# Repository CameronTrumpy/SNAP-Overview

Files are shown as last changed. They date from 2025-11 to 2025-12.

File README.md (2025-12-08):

# SNAP-Overview

SNAP-Overview is our central repository storing all of the relevant information for SNAP, the low-cost modular electronics workstation.

## SNAP-Overview Content
- [Firmware](./Firmware)
    - Mainboard Module Code
    - Oscilloscope / Logic Analyzer Module Code
    - Power Supply / Waveform Generator Module Code
- [docs](./docs)
    - Code for [snapstation.tech](https://snapstation.tech), our project overview website
    - [In-browser demo of our user interface](https://snapstation.tech/demo.html)
- [Hardware](./Hardware)
    - PDF prints of our schematics for all three modules
    - Altium Project archives
    - Translated KiCad Project archived
    - STEP models of the PCB housings
- [WebUI](./WebUI)
    - The frontend and backend for our web-based user interface
- [SigrokPatch](./SigrokPatch)
    - Our modified version of [Sigrok](http://sigrok.org) with support for SNAP
## Contributors
- [Claire Garbowski](https://www.linkedin.com/in/claire-garbowski/)
- [Ethan McKean](https://www.linkedin.com/in/ethanmckean/)
- [Andre Quimper Osores](https://www.linkedin.com/in/andre-q-395964254/)
- [Jack Smith](http://www.linkedin.com/in/jack-smith-561326330)
- [Cameron Trumpy](https://www.linkedin.com/in/cameron-trumpy/)
- [Benjamin Wolin](https://www.linkedin.com/in/benjamin-wolin-8812aa1ab/)

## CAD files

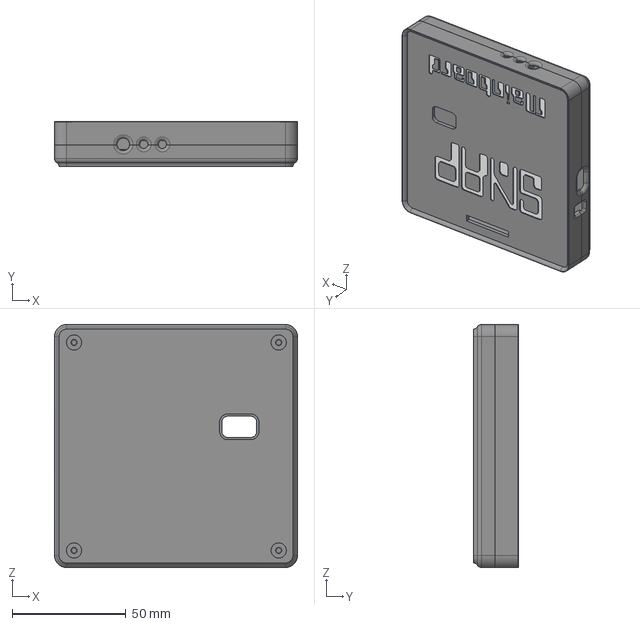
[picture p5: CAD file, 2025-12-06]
Hardware/Mainboard/Mainboard_Housing.step
107.0 x 19.9 x 107.0 mm
Base

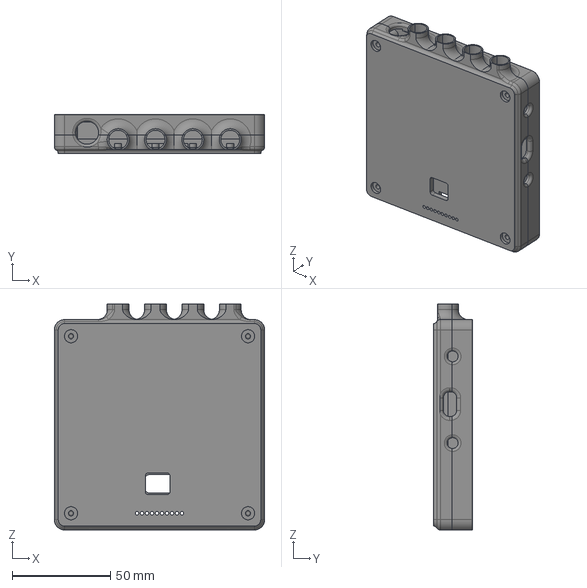
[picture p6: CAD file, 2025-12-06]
Hardware/PD_Waveform/PSU_Housing.step
107.0 x 19.9 x 114.9 mm
Base

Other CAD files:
Hardware/LA_OS/Scope_Housing.step

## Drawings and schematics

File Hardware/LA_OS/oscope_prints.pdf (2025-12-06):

# Mode Pin Settings

# REF Decoupling

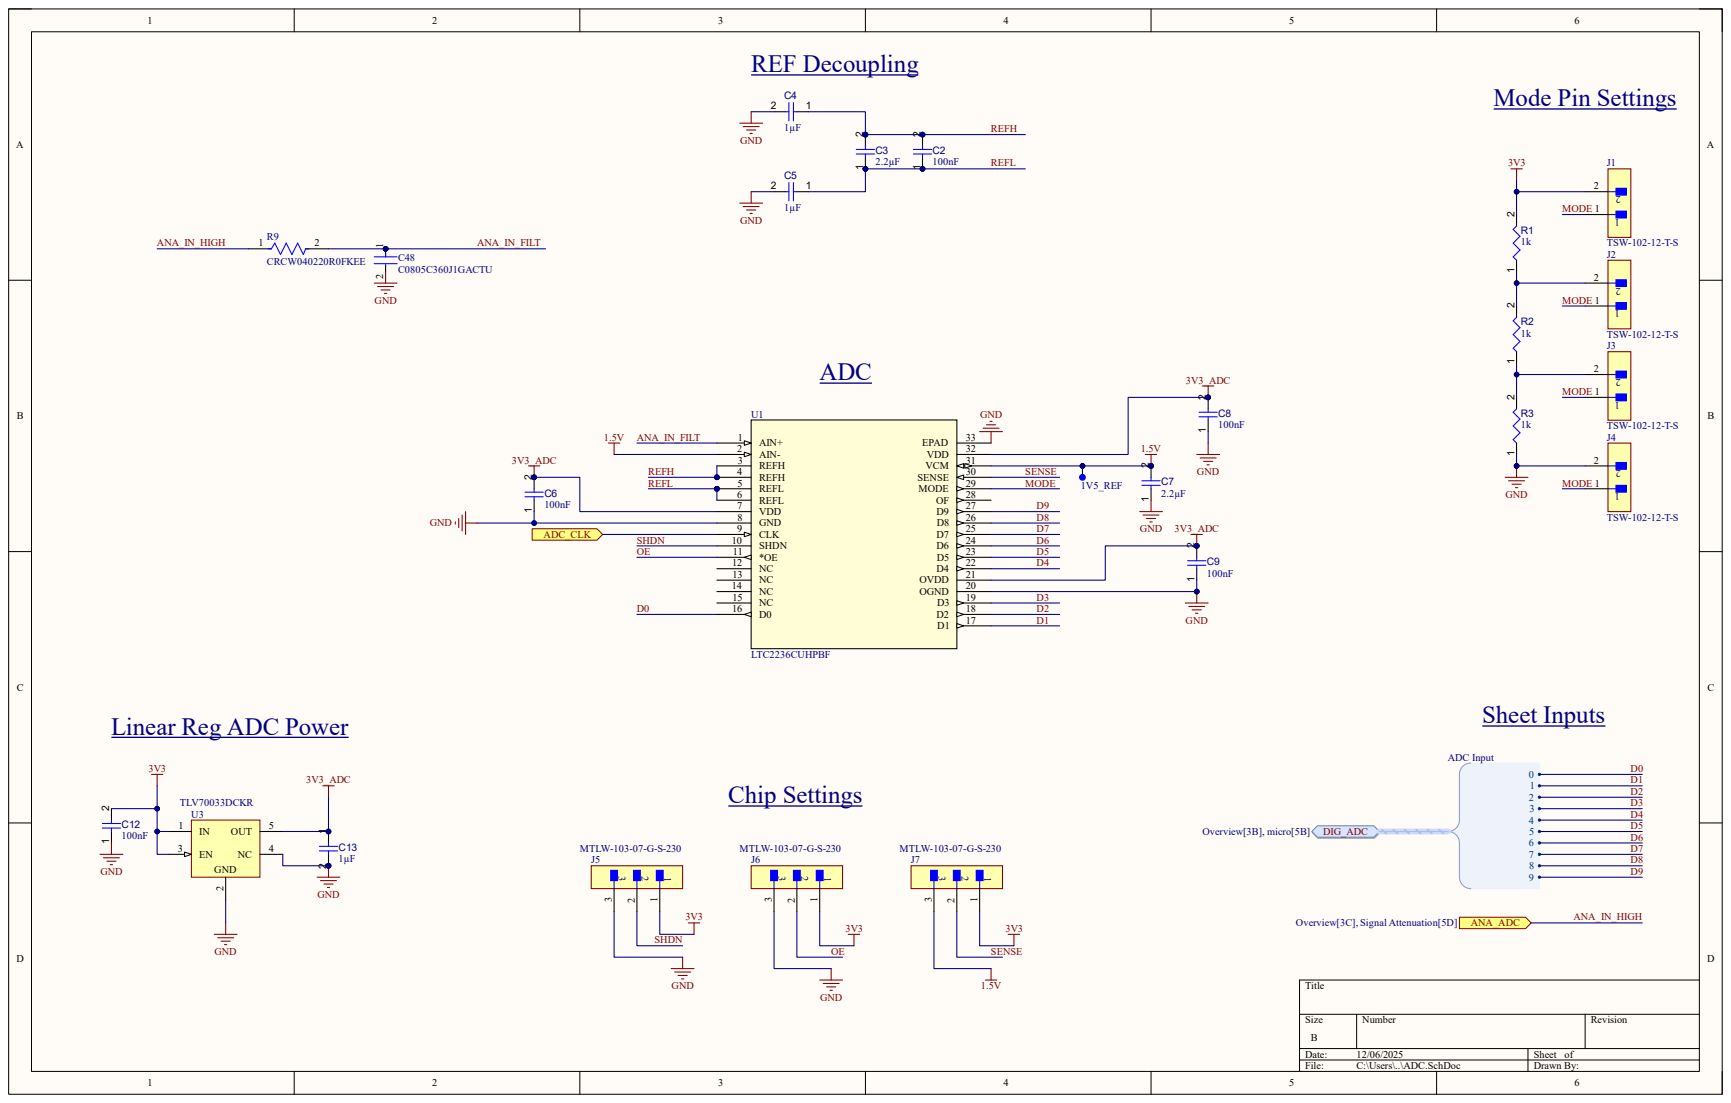
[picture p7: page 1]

Linear Reg ADC Power

A A

ANA_IN | ANA_IN

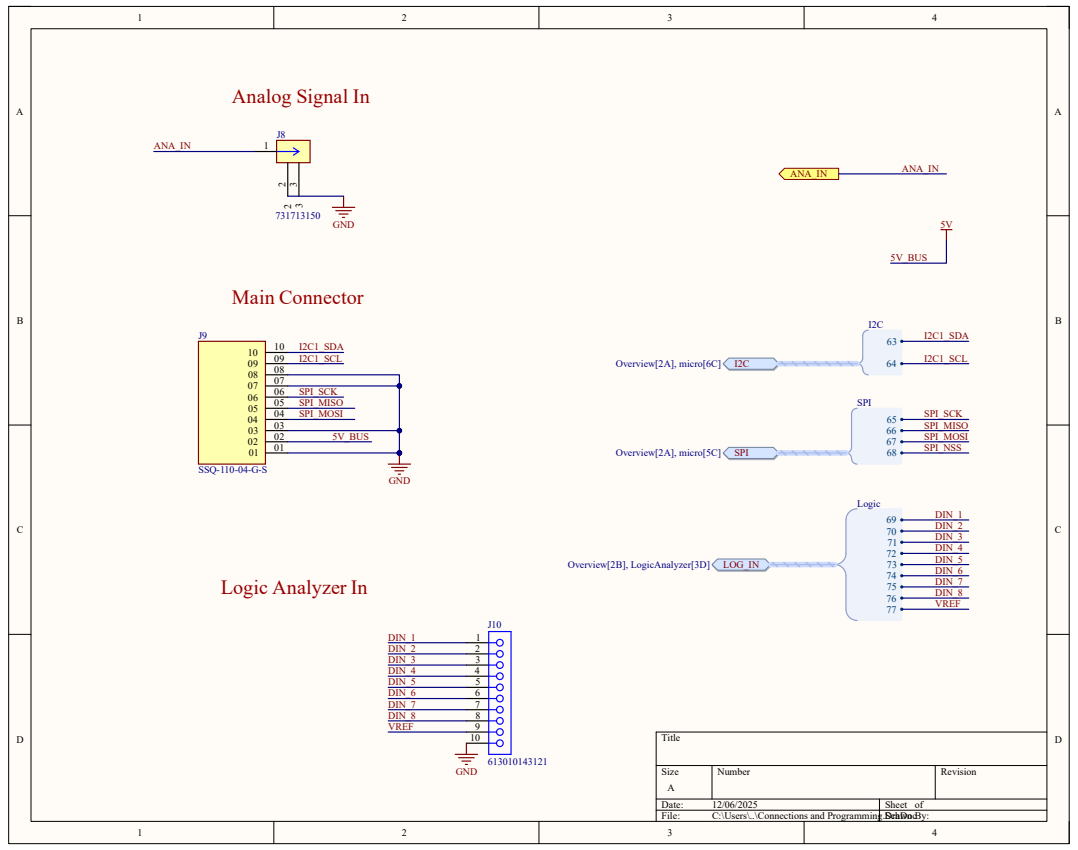
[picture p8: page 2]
Title; Size; Number; Revision; Date:; Sheet of; File:; C:\Users\..\Connections and Programming.SchDoc Drawn By:; GND; I2C1_SCL; 5V_BUS; I2C1_SDA; SPI_SCK; SPI_MOSI; SPI_MISO; I2C1_SCL Overview[2A], micro[6C] I2C; SPI; SPI_SCK SPI_MISO SPI_MOSI; ANA_IN; Logic; Overview[2B], LogicAnalyzer[3D] LOG_IN; DIN_1 DIN_2 DIN_3 DIN_4 DIN_5 DIN_6 DIN_7 DIN_8; Main Connector; SSQ-110-04-G-S; VREF

Analog Signal In

SPI_NSS Overview[2A], micro[5C] SPI

Logic Analyzer In

Level Shifter | Input ESD Protection

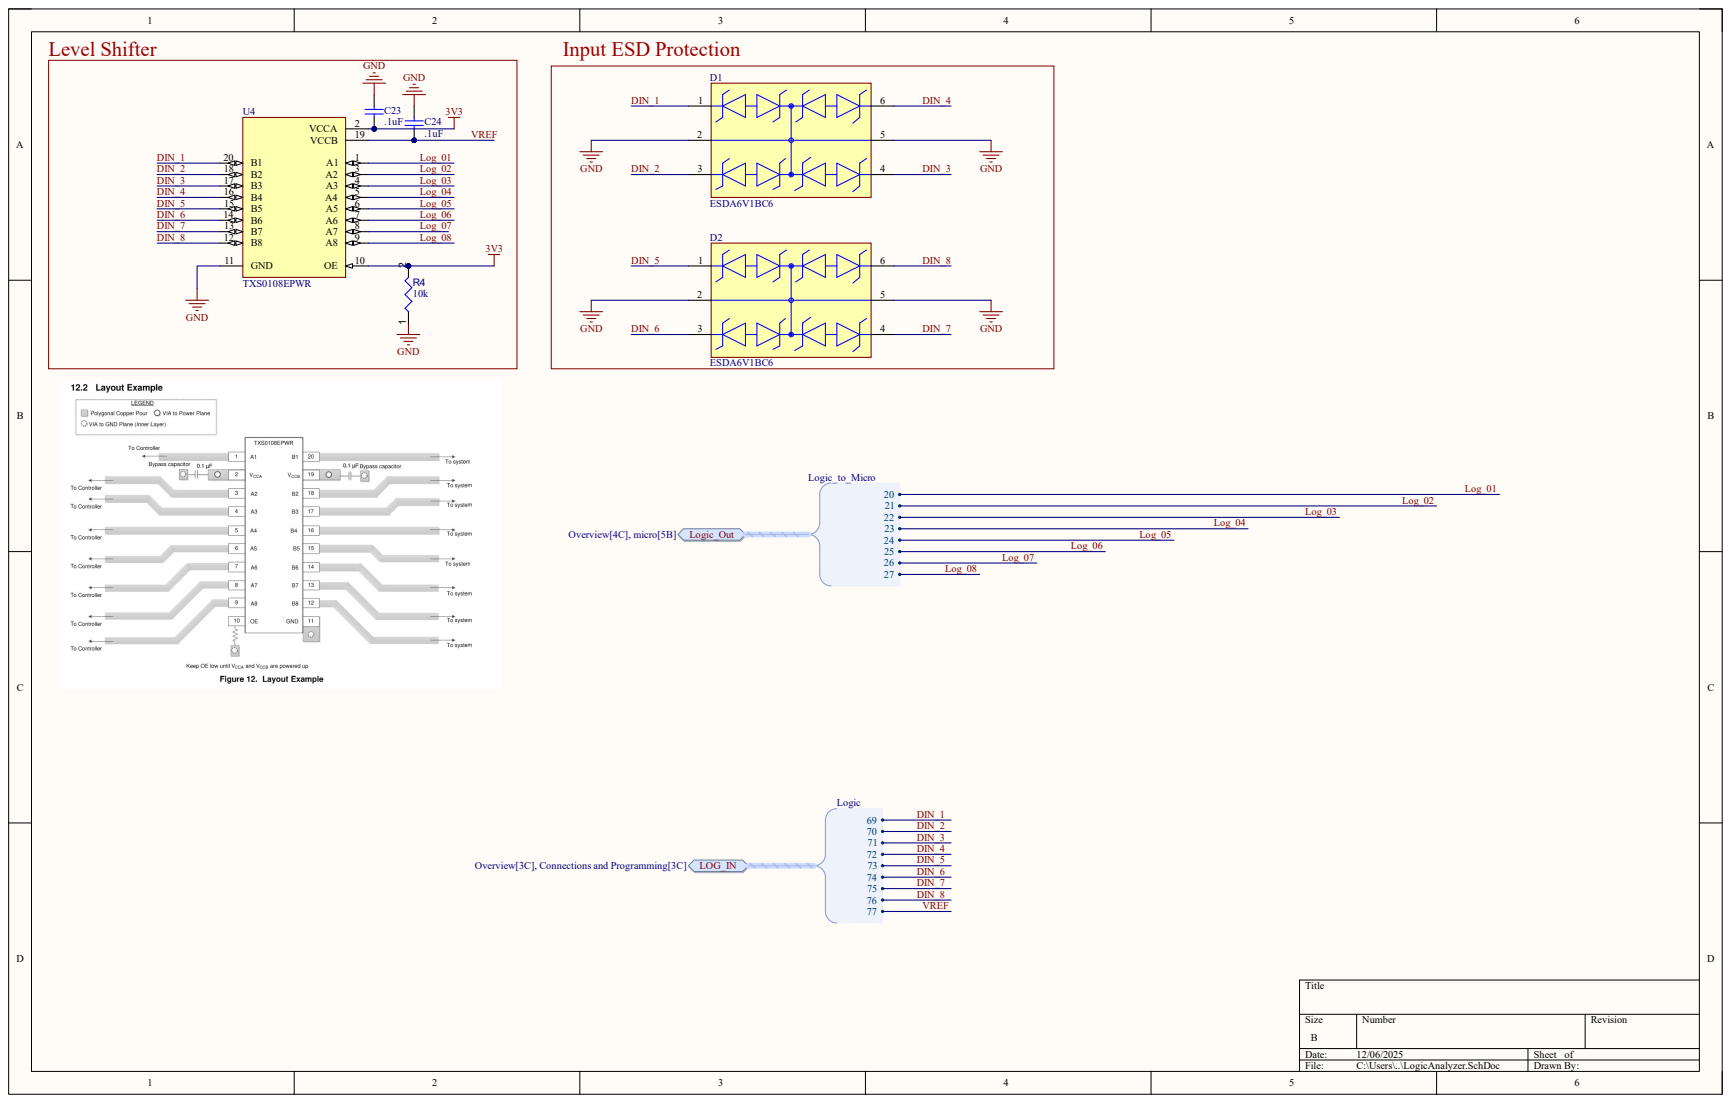
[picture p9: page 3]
Title; Size; Number; Revision; Date:; Sheet of; File:; C:\Users\..\LogicAnalyzer.SchDoc; Drawn By:; Log_01 Log_02 Log_03 Log_04 Log_05 Log_06 Log_07 Log_08; ESDA6V1BC6; DIN_1; DIN_2; DIN_3; DIN_4; DIN_5; DIN_6; DIN_7; DIN_8; GND; DIN_1 DIN_2 DIN_3 DIN_4 DIN_5 DIN_6 DIN_7 DIN_8; VCCA; VCCB; 10 GND 11; TXS0108EPWR; VREF 2 1; Logic_to_Micro; Overview[4C], micro[5B] Logic_Out; Log_01; Log_02; Log_03; Log_04; Log_05; Log_06; Log_07; Log_08; Logic; DIN_1 DIN_2 DIN_3 DIN_4 DIN_5 DIN_6 DIN_7 DIN_8 VREF

Overview[3C], Connections and Programming[3C] LOG_IN

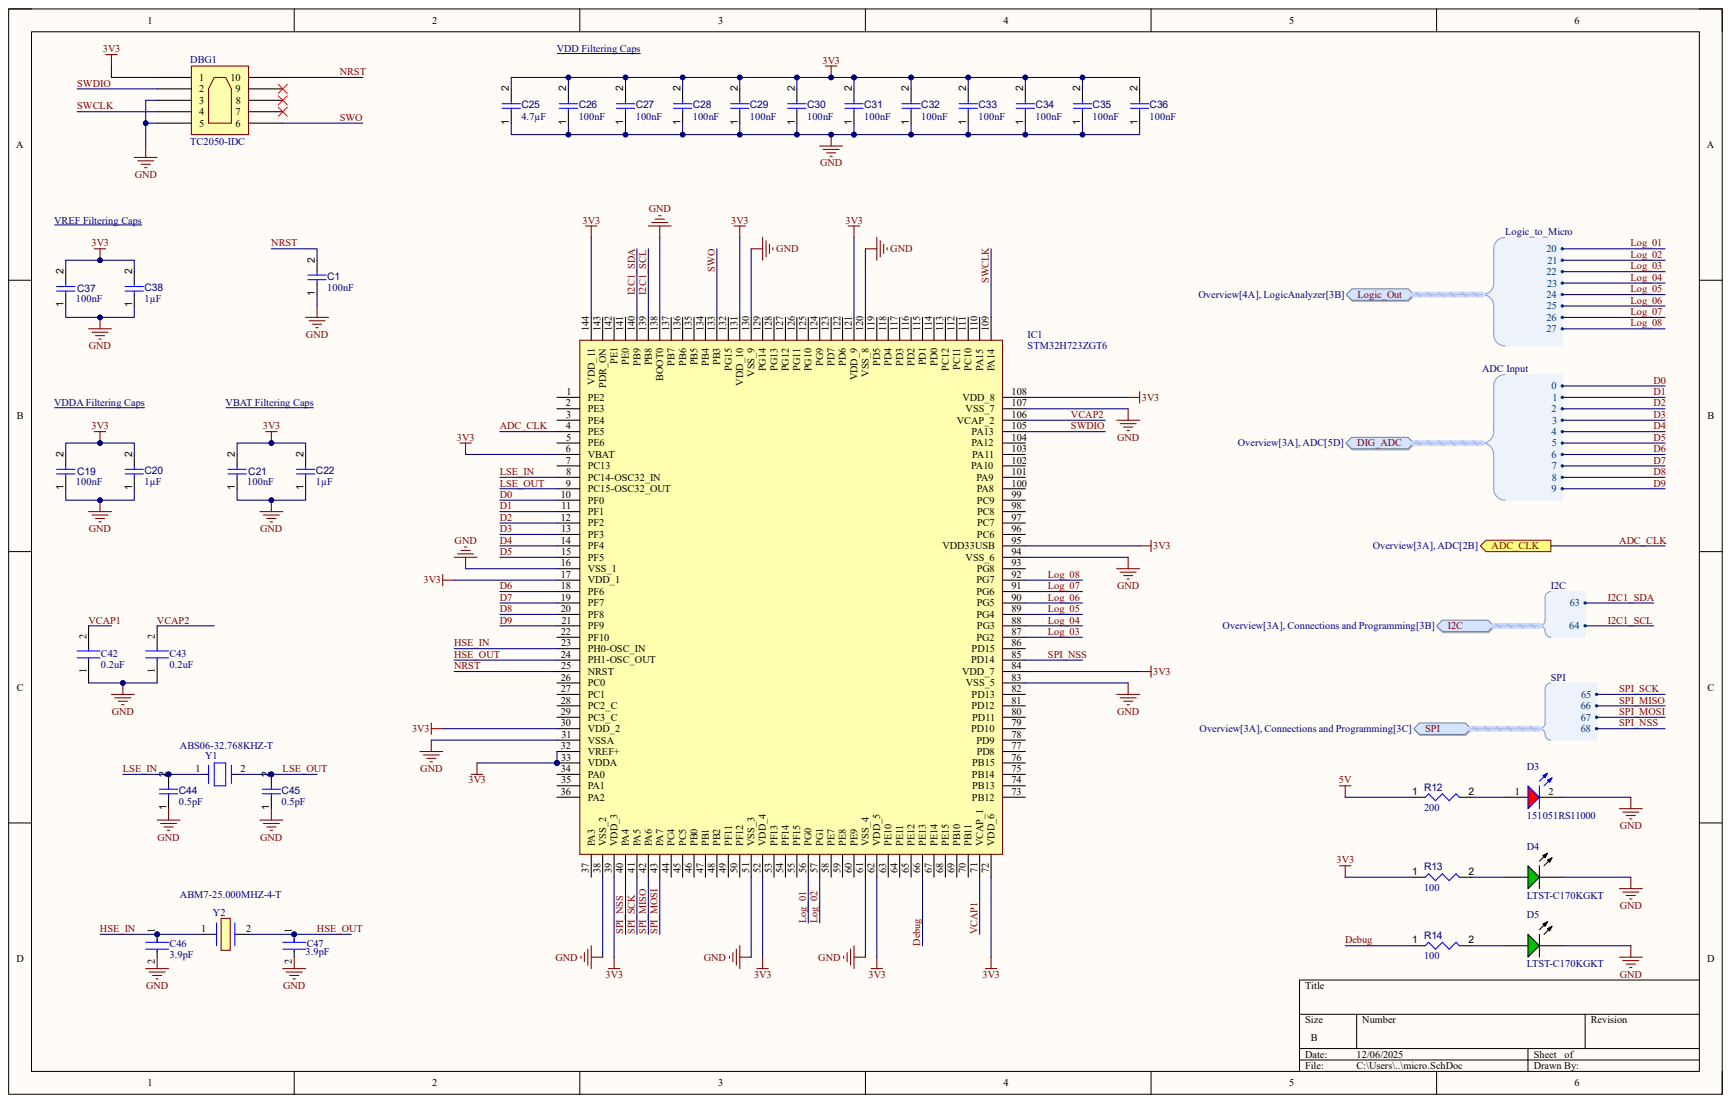
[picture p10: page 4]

I2C1_SCL Overview[3A], Connections and Programming[3B] I2C I2C¹_SDA I2C¹_SCL

SPI_NSS Overview[3A], Connections and Programming[3C] SPI SPI_NSS SPI_SCK SPI_MISO SPI_MOSI

A A

## SPI

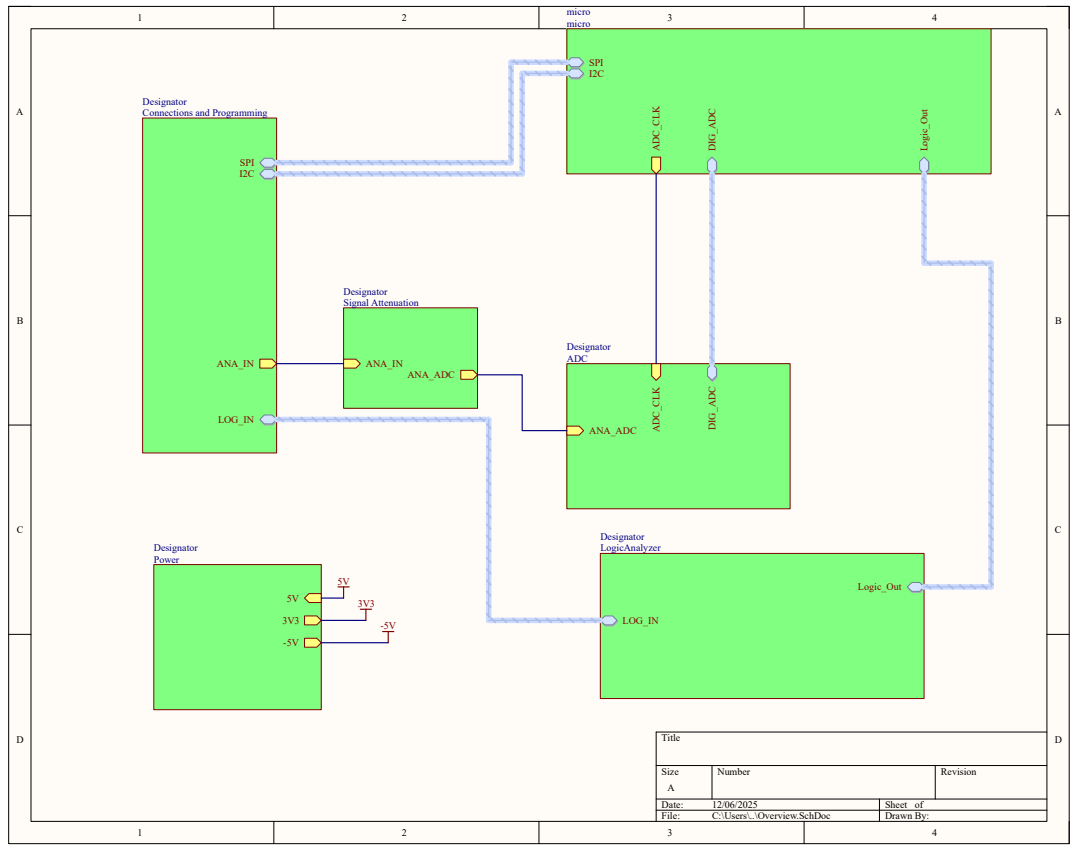
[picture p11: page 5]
Title; Size; Number; Revision; File:; C:\Users\..\Overview.SchDoc; Drawn By:; ANA_IN; LOG_IN; Designator; Connections and Programming; ADC_CLK; DIG_ADC; Logic_Out; SPI I2C; micro; DIG_ADC ANA_ADC; Designator ADC; Designator LogicAnalyzer; Designator Power; ANA_ADC; Designator Signal Attenuation

A A

## SD 1 V+ 8

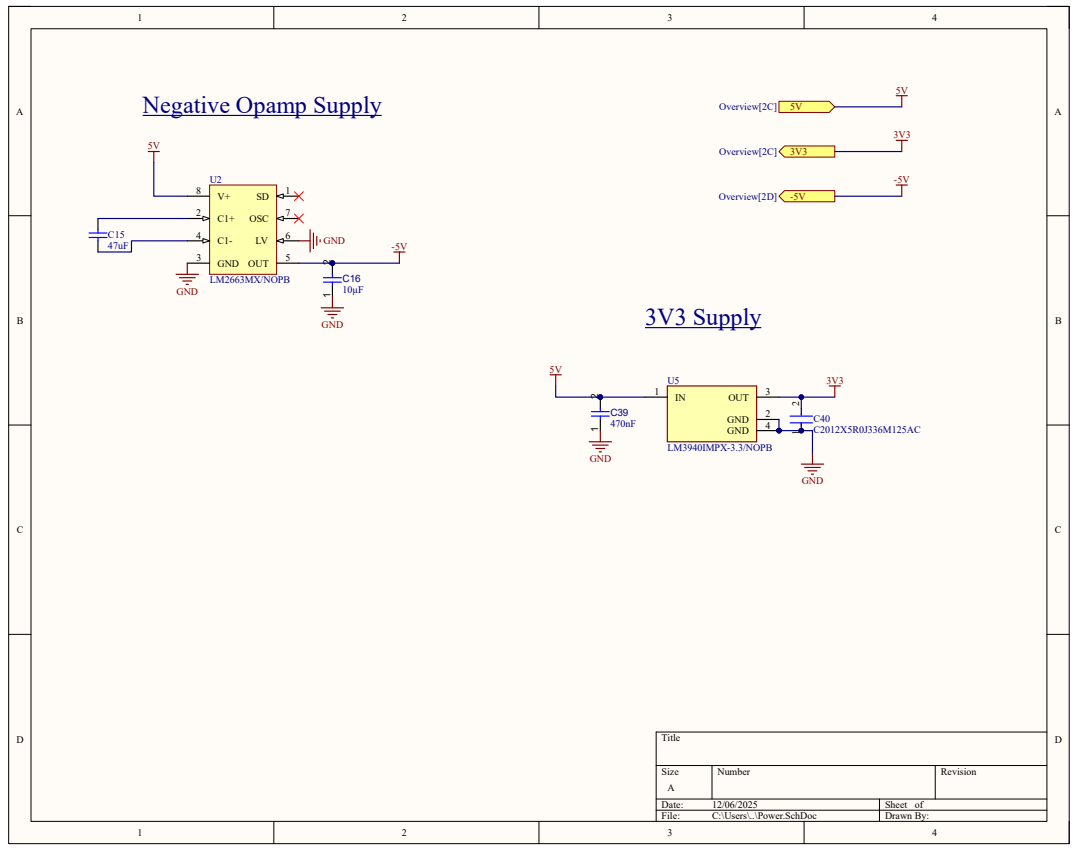
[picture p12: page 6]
Title; Size; Number; Revision; File:; C:\Users\..\Power.SchDoc; Drawn By:; GND 3; OUT; OSC; LM2663MX/NOPB; GND; GND1 2; LM3940IMPX-3.3/NOPB; GND ¹ ²; 3V3 Supply; Overview[2C] 5V; Overview[2C] 3V3; Overview[2D] -5V

Negative Opamp Supply

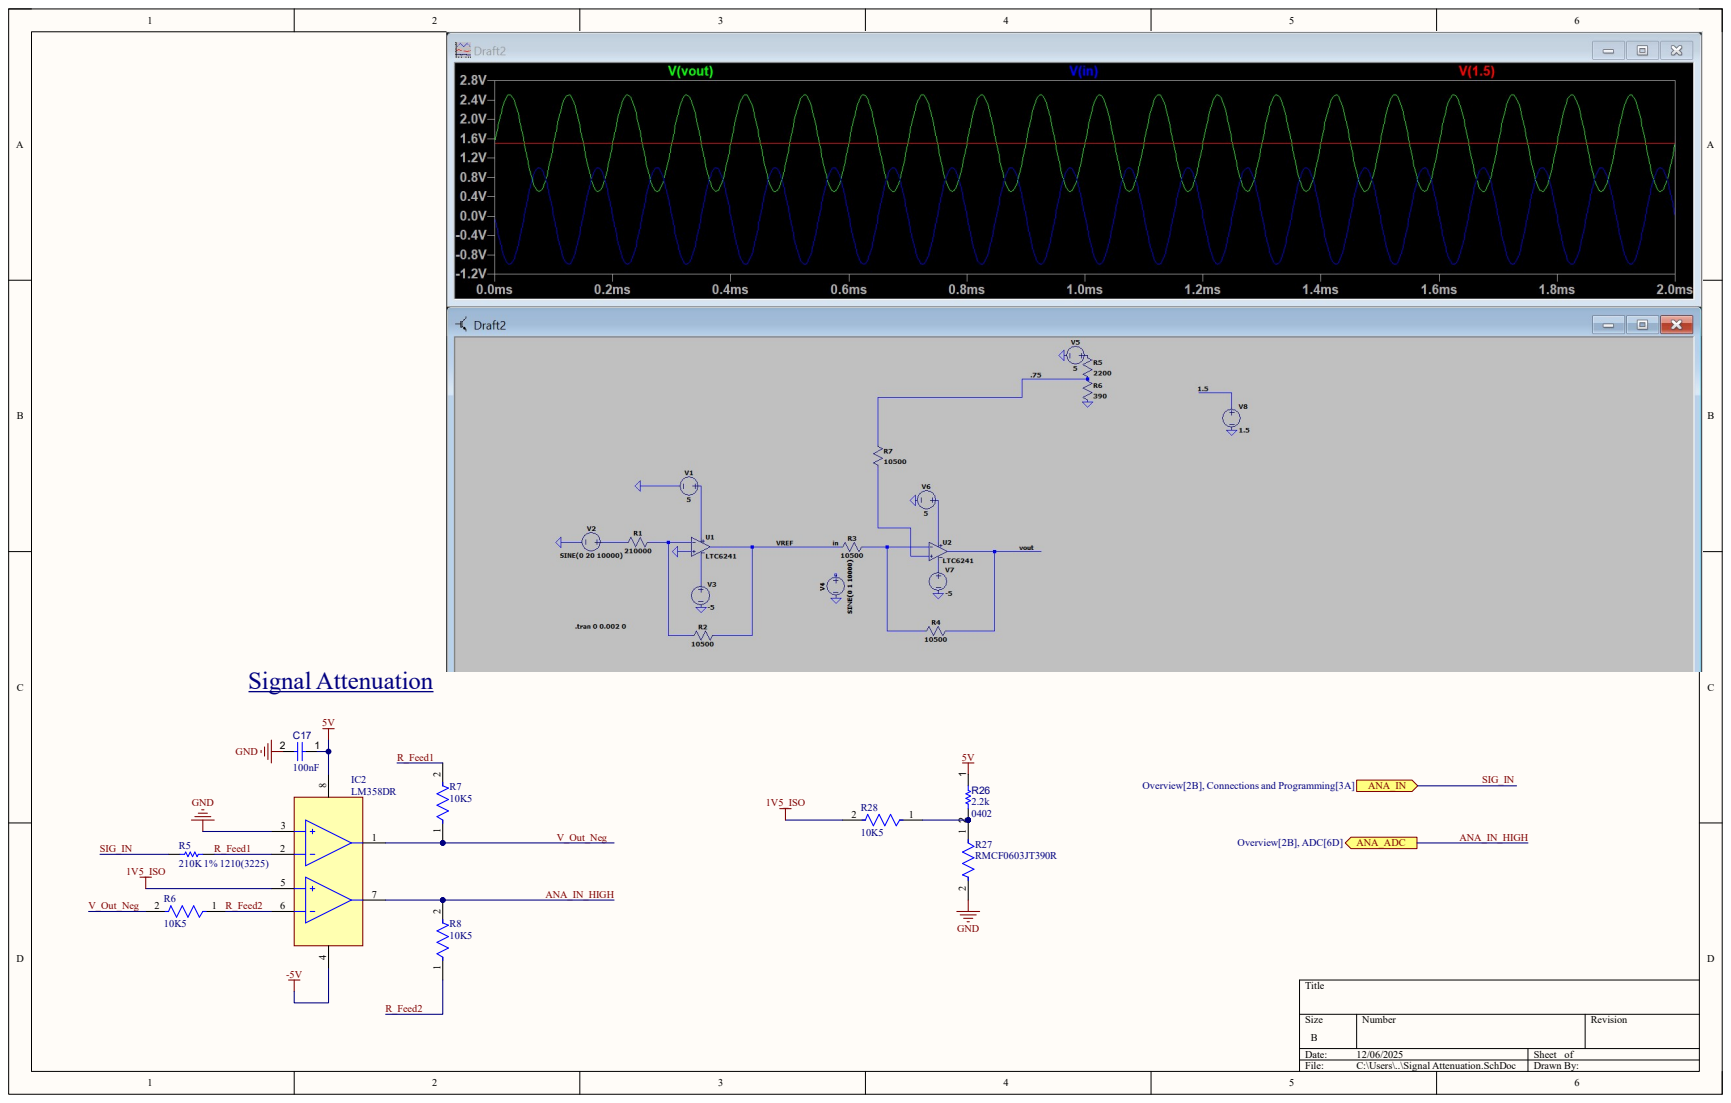
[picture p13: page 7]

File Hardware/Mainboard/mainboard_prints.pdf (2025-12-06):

1

2

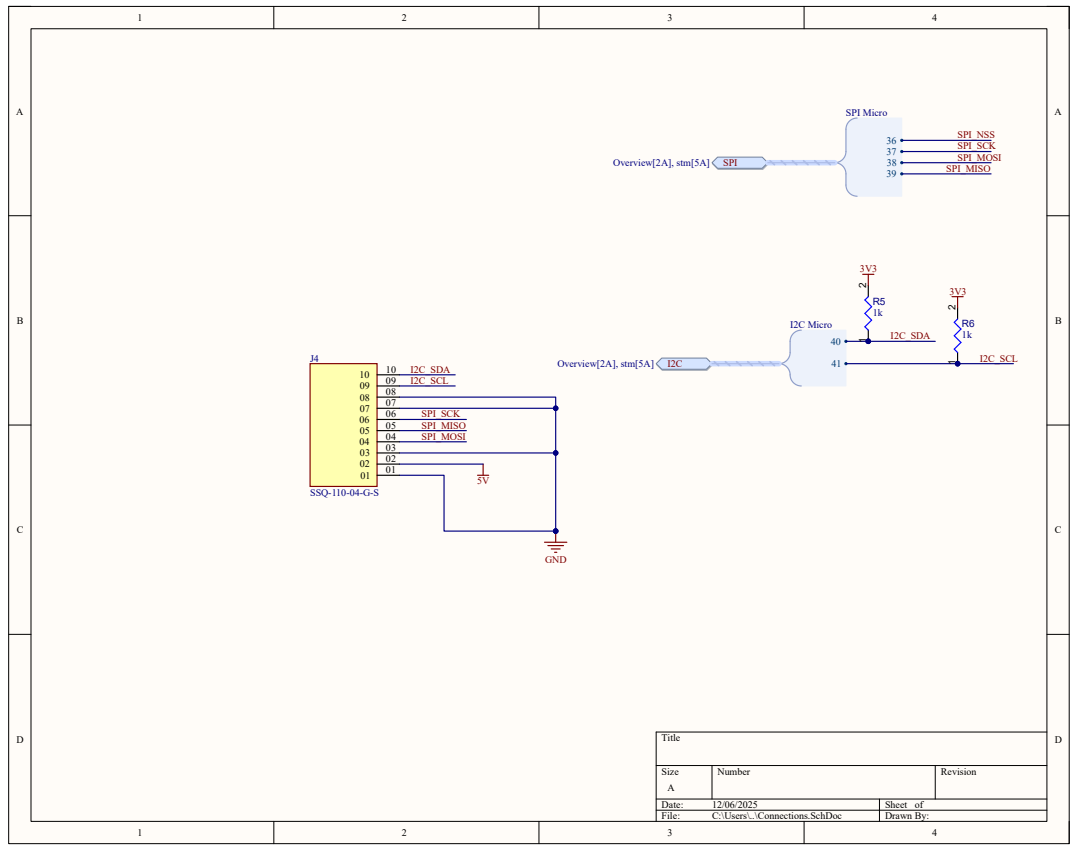
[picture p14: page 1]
Title; Size; Number; Revision; Date:; Sheet of; File:; C:\Users\..\Connections.SchDoc; Drawn By:; SPI Micro; SPI_NSS SPI_SCK; I2C Micro; Overview[2A], stm[5A] I2C; I2C_SDA; I2C_SCL; SPI_MOSI; GND; SPI_SCK; SPI_MISO; SSQ-110-04-G-S

SPI_MISO Overview[2A], stm[5A] SPI

1

2

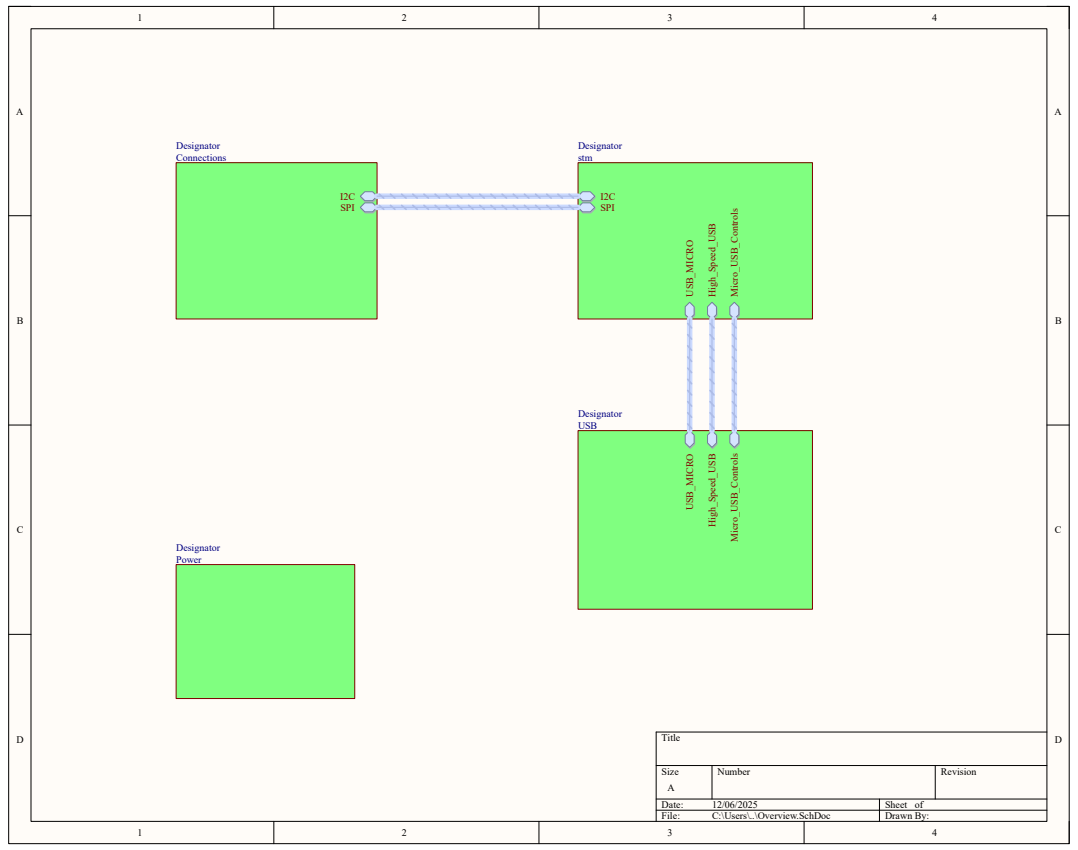
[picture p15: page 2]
Title; Size; Number; Revision; Date:; Sheet of; File:; C:\Users\..\Overview.SchDoc; Drawn By:; I2C SPI; Designator Connections; SPI; USB_MICRO; High_Speed_USB; Micro_USB_Controls; Designator; stm; Designator USB; Designator Power

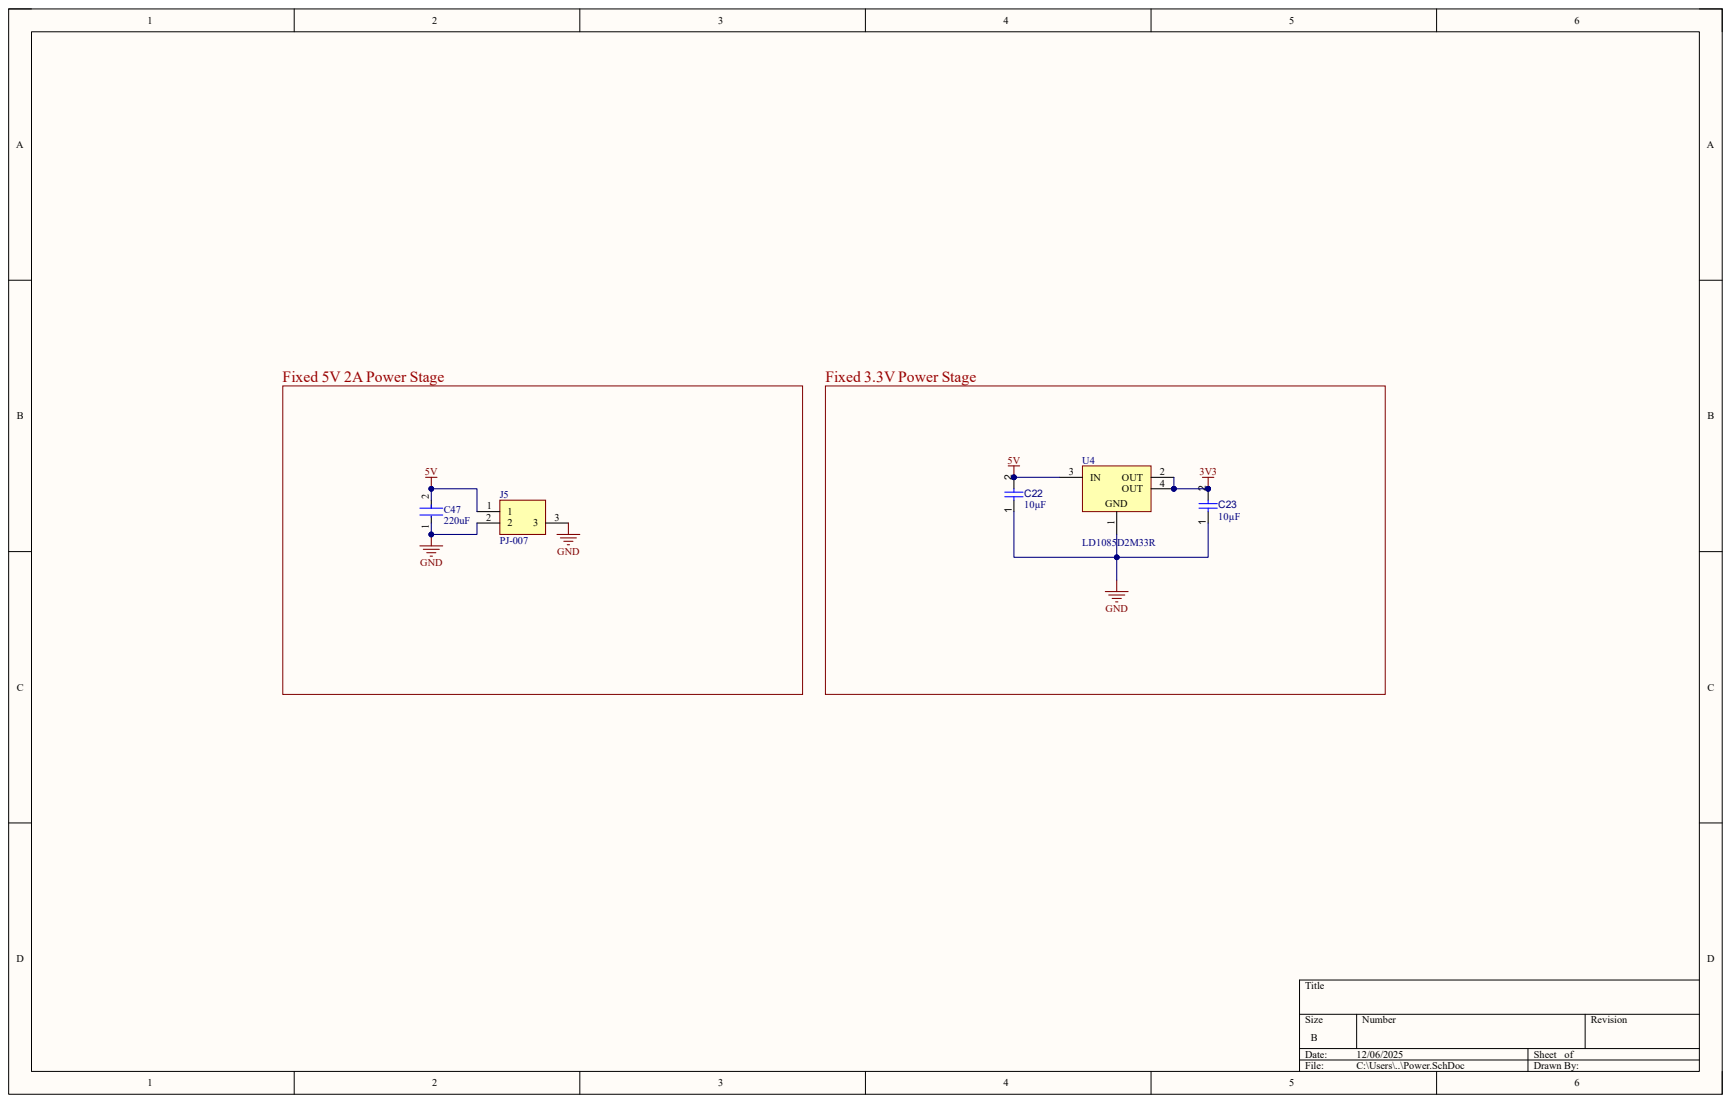
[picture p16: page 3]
Title; Size; Number; Revision; Date:; Sheet of; File:; C:\Users\..\Power.SchDoc; Drawn By:; Fixed 5V 2A Power Stage; Fixed 3.3V Power Stage; GND; OUT

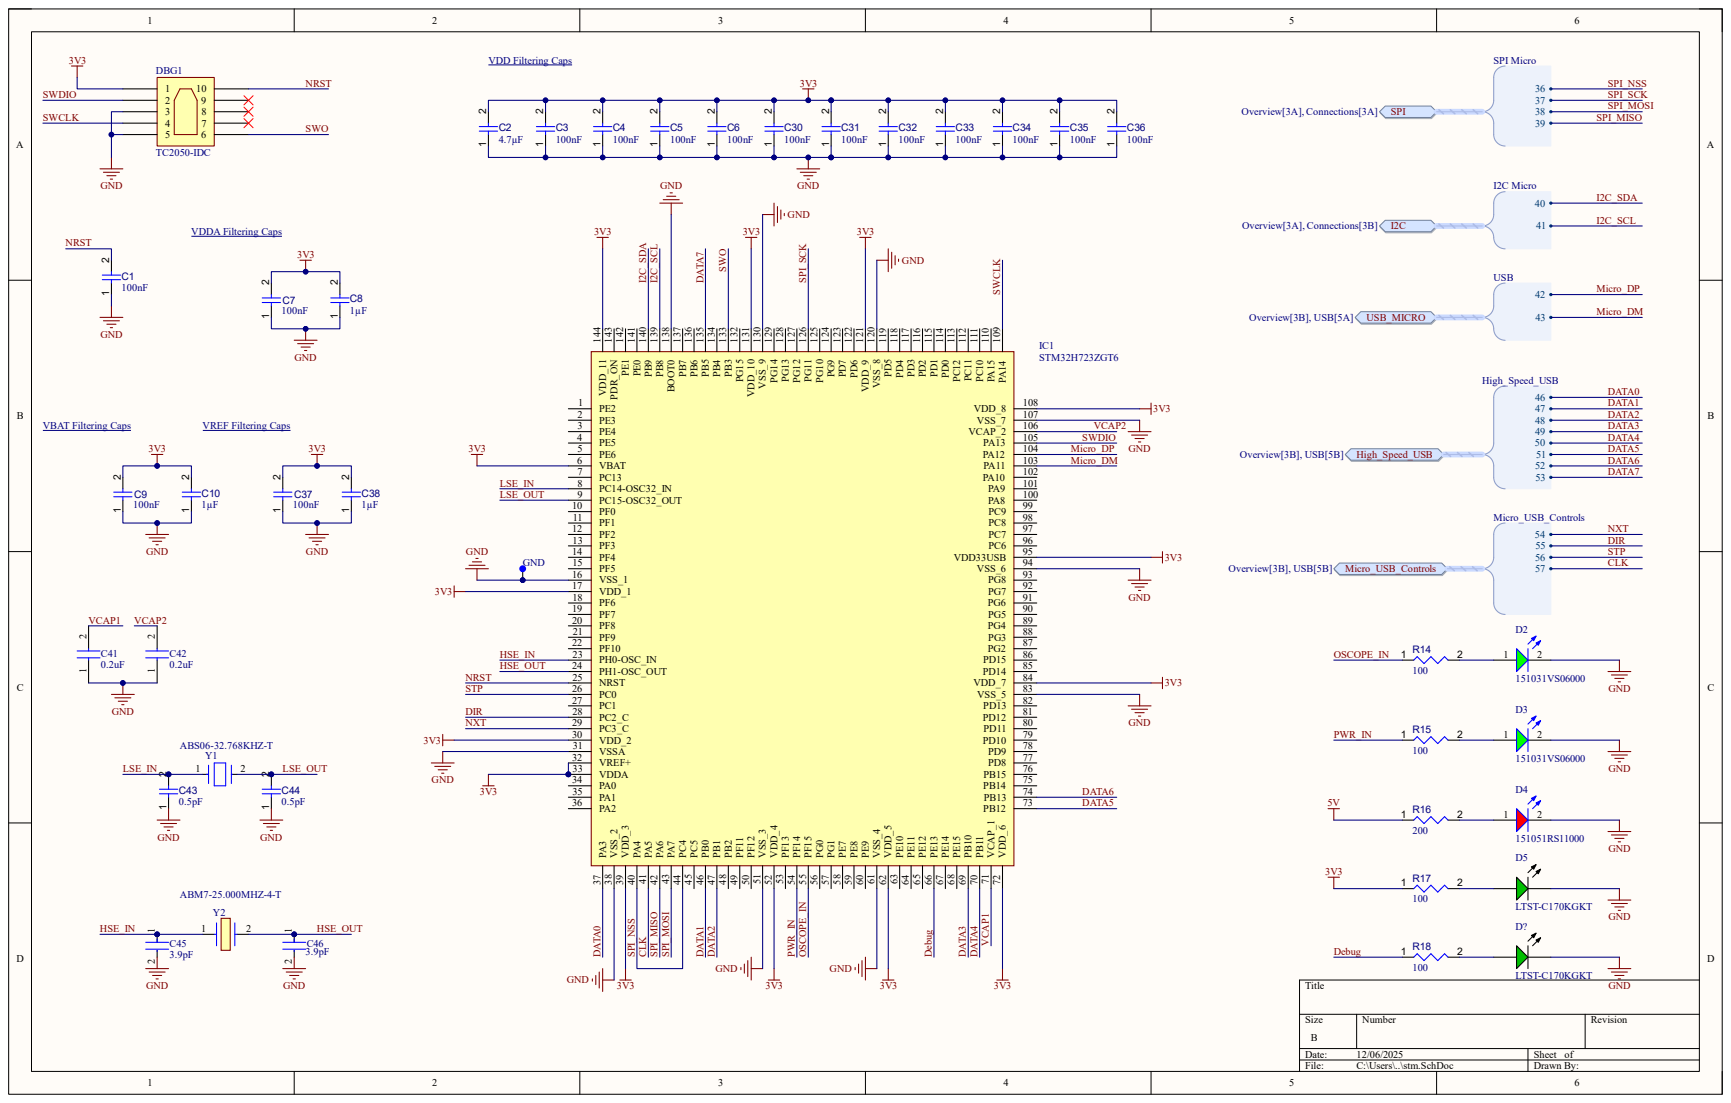
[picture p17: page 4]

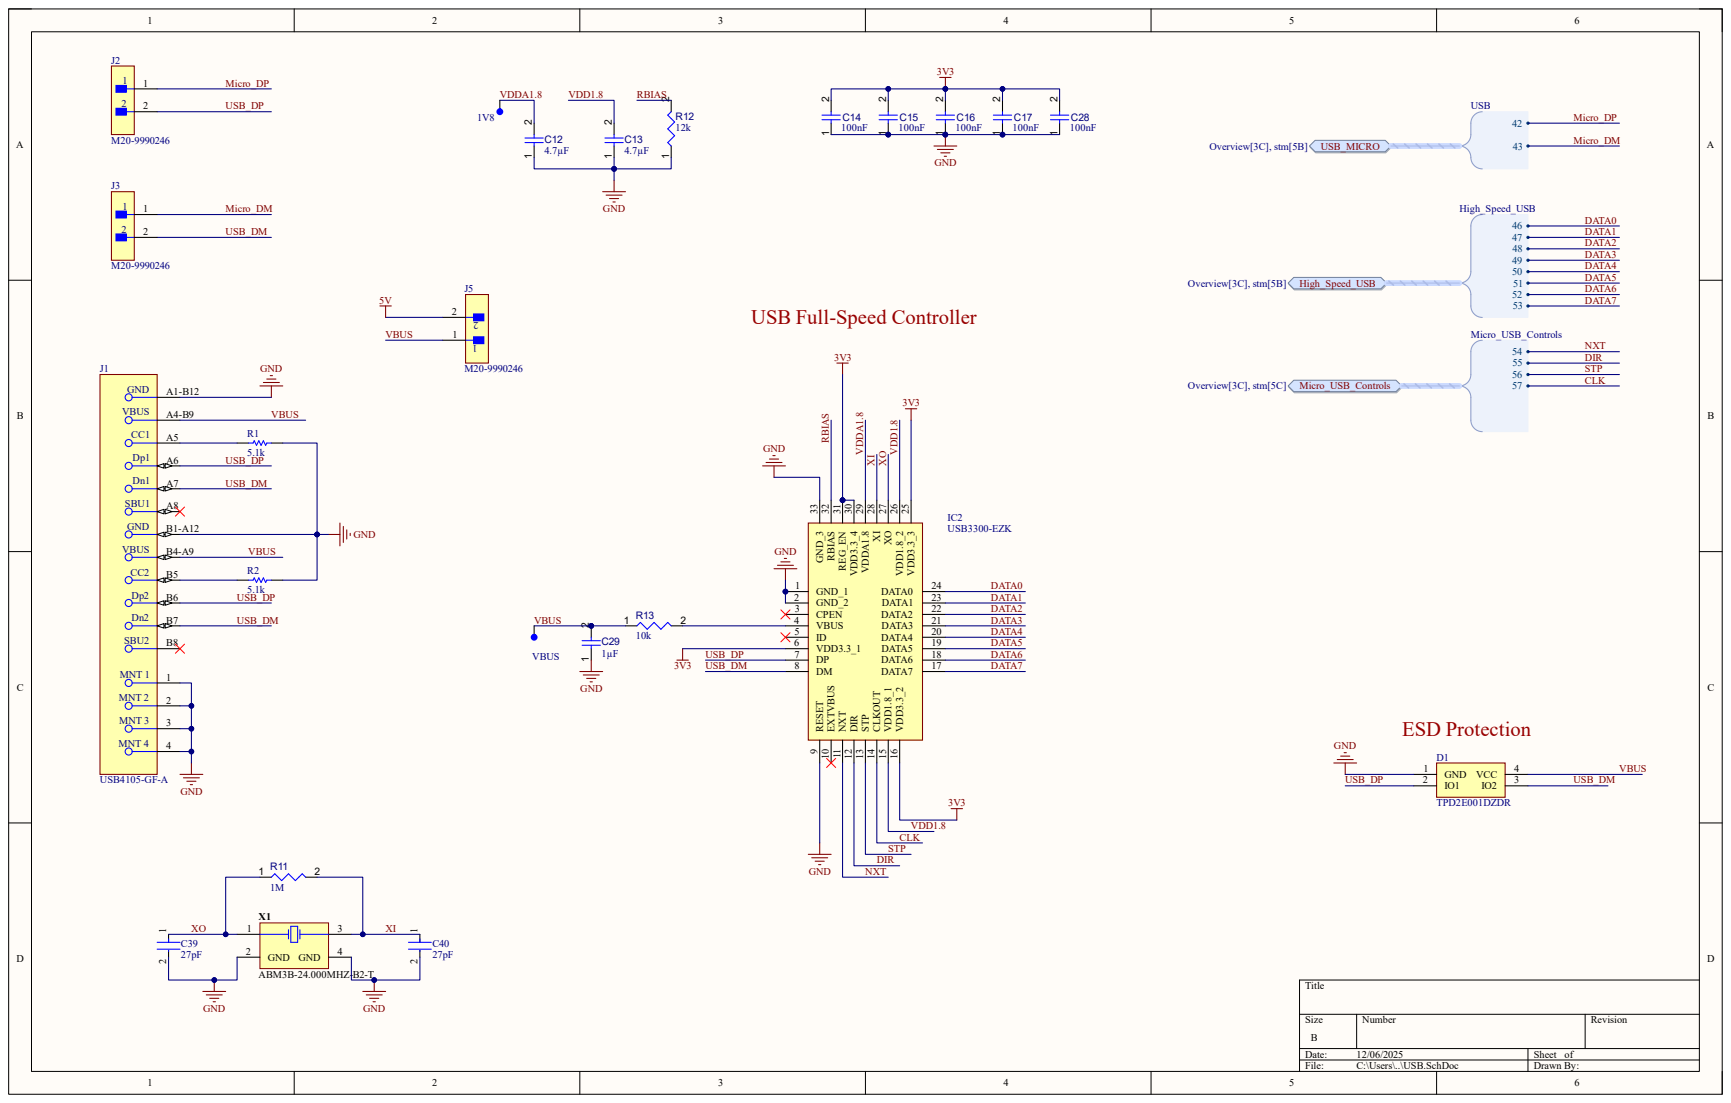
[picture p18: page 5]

USB Full-Speed Controller
VDD1.8 VDDA¹.8

9 EXTVBUS 10 NXT 11 DIR 12 STP 13 CLKOUT 14 VDD1.8_1 15 VDD3.3_2 16

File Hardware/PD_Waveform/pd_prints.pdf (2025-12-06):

REVISION | DESCRIPTION | DATE | APPROVED | REV. SHT. <SCH DWG NO> 1 DWG. NO.


8 | 7 | 6 | 5 | 4 | 3 | <SCH DWG NO> | DWG. NO. | REV. | 1 SHT. | 2 | 1

THIS DOCUMENT AND THE DATA DISCLOSED HEREIN OR HEREWITH IS THE PROPERTY OF ALTIUM LIMITED AND MAY BE FREELY DISTRIBUTED IN WHOLE. NO RIGHTS ARE RESERVED OR EXPRESS OR IMPLIED WARANTEE GIVEN. | 3V3

SNAP - Power Supply / Waveform Generator Module

Power Supply Control Lines

APPROVALS | DATE | PROJECT * | * *

ENG: * | --/--/--
CHK: * | --/--/-- | TITLE *

DSN: * | --/--/--

# GND¹ ²


Onboard 3.3V LDO Linear Voltage Regulator

ST-Link Programmer Interface

## -5V Charge Pump


50 Ohm Impedance Output On BNC Connector WAV_RAW

VR1 added in Rev2, allows for minor output tuning adjustments.

https://www.ti.com/lit/ug/tiduct8/tiduct8.pdf

Adapted from CentyLab RotoPD - Design adapted under CC Share-alike 4.0 License.

## GND¹ ²


9 NC_3 10 NC_4 11 V18 12 OTP 13 NC_5 14 IFB 15 CC2 16 CC1 17 DN 18 DP 19 V5V 20 NC_6 21 VOUT 22 PWR_EN 23 VCC 24 GND_2 25

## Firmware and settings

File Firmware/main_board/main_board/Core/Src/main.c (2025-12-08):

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
/* Includes ------------------------------------------------------------------*/
#include "main.h"

#include "cmsis_os.h"

/* USER CODE BEGIN Includes */
#include <ctype.h>
#include <stdio.h>
#include <string.h>

#include "la_os_commands.h"
#include "packet.h"
#include "snap_master.h"
#include "snap_pd_master.h"
#include "snap_wf_master.h"
#include "tusb.h"
#include "wavetypes.h"
/* USER CODE END Includes */

/* USER CODE BEGIN PD */
#define CDC_MAIN 0
#define CDC_SIGROK 1

// Task stack sizes (in words, 4 bytes each)
#define USBD_STACK_SIZE (2048)
#define SUMP_STACK_SIZE (1024)
#define COMMAND_STACK_SIZE (1024)
/* USER CODE END PD */


COM_InitTypeDef bsp_com_init;

I2C_HandleTypeDef hi2c1;

SPI_HandleTypeDef hspi1;
DMA_HandleTypeDef hdma_spi1_rx;

UART_HandleTypeDef huart1;

PCD_HandleTypeDef hpcd_USB_OTG_HS;

/* Definitions for defaultTask */
osThreadId_t defaultTaskHandle;
const osThreadAttr_t defaultTask_attributes = {
    .name = "defaultTask",
    .stack_size = 256 * 4,
    .priority = (osPriority_t)osPriorityNormal,
};
/* USER CODE BEGIN PV */

osThreadId_t chunkTaskHandle;
osSemaphoreId_t chunkStartSemaphore;
osMutexId_t chunkRequestMutex;
osMutexId_t usb_flush_mutex;
osSemaphoreId_t processCommandSemaphore;

static volatile uint32_t num_chunks_requested = 0;
static volatile uint8_t chunk_task_running = 0;
static volatile uint8_t chunk_cdc_port = CDC_MAIN;
static volatile uint8_t chunk_cancel_requested = 0;
static volatile CommandCode chunk_command =
    COMMAND_OS_GET_CHUNK;  // track if scope or LA data requested

// FreeRTOS task handles
osThreadId_t usbTaskHandle;
osThreadId_t sumpTaskHandle;
osThreadId_t commandTaskHandle;

// Task attributes
const osThreadAttr_t usb_task_attributes = {
    .name = "usb_device",
    .stack_size = USBD_STACK_SIZE * 4,
    .priority = (osPriority_t)osPriorityRealtime7,
};

const osThreadAttr_t command_task_attributes = {
    .name = "command_handler",
    .stack_size = COMMAND_STACK_SIZE * 4,
    .priority = (osPriority_t)osPriorityHigh,
};

const osThreadAttr_t chunk_task_attr = {
    .name = "chunk_streamer",
    .stack_size = 1024 * 4,
    .priority = (osPriority_t)osPriorityAboveNormal,
};

// Mutexes for resource protection
osMutexId_t i2cMutexHandle;
osSemaphoreId_t spiSemaphoreHandle;

const osMutexAttr_t mutex_attributes = {
    .name = NULL,
    .attr_bits = osMutexRecursive | osMutexPrioInherit,
    .cb_mem = NULL,
    .cb_size = 0U};

#include "bsp/board_api.h"

size_t board_get_unique_id(uint8_t id[], size_t max_len) {
    (void)max_len;
    volatile uint32_t* stm32_uuid = (volatile uint32_t*)UID_BASE;
    uint32_t* id32 = (uint32_t*)(uintptr_t)id;
    uint8_t const len = 12;

    id32[0] = stm32_uuid[0];
    id32[1] = stm32_uuid[1];
    id32[2] = stm32_uuid[2];

    return len;
}

/* USER CODE END PV */

void SystemClock_Config(void);
static void MPU_Config(void);
static void MX_GPIO_Init(void);
static void MX_DMA_Init(void);
static void MX_USART1_UART_Init(void);
static void MX_I2C1_Init(void);
static void MX_SPI1_Init(void);
static void MX_USB_OTG_HS_PCD_Init(void);
void StartDefaultTask(void* argument);

/* USER CODE BEGIN PFP */
// FreeRTOS task functions
void usb_device_task(void* param);
void command_handler_task(void* param);

int send_example_waveform(enum WaveformType type);
/* USER CODE END PFP */

/* USER CODE BEGIN 0 */

// Invoked when device is mounted
void tud_mount_cb(void) {
    // Device mounted
}

// Invoked when device is unmounted
void tud_umount_cb(void) {
    // Device unmounted
}

// Invoked when usb bus is suspended
void tud_suspend_cb(bool remote_wakeup_en) {
    (void)remote_wakeup_en;
    // Device suspended
}

// Invoked when usb bus is resumed
void tud_resume_cb(void) {
    // Device resumed
}

struct GetChunkResponse {
    uint32_t chunk_number;  // Sequential chunk ID
    uint32_t samples_available;
    uint32_t missed_chunks;
};

uint8_t sample_buffer[SAMPLE_BUF_SIZE] __attribute__((section(".sram_d1"))) = {0};

/**
 * @brief Send OK response with optional payload data
 * @param cdc_interface: CDC interface number (CDC_MAIN or CDC_LOGIC)
 * @param data: Optional payload data (can be NULL if len is 0)
 * @param len: Length of payload data (0-255)
 */
static void send_ok_response(uint8_t cdc_interface, uint8_t* data, uint8_t len) {
    PacketResponseHeader header;
    header.start_marker = PACKET_START_MARKER_RESPONSE;
    header.status = PACKET_STATUS_OK;
    header.payload_length = len;

    osMutexAcquire(usb_flush_mutex, osWaitForever);
    // Send header
    tud_cdc_n_write(cdc_interface, (uint8_t*)&header, PACKET_HEADER_SIZE);

    // Send payload if present
    if (len > 0 && data != NULL) {
        tud_cdc_n_write(cdc_interface, data, len);
    }

    tud_cdc_n_write_flush(cdc_interface);
    osMutexRelease(usb_flush_mutex);
}

/**
 * @brief Send error response with error code
 * @param cdc_interface: CDC interface number (CDC_MAIN or CDC_LOGIC)
 * @param snap_error: SNAP error code (negative value)
 */
static void send_error_response(uint8_t cdc_interface, int8_t snap_error) {
    PacketResponseHeader header;
    header.start_marker = PACKET_START_MARKER_RESPONSE;
    header.status = snap_error_to_packet_status(snap_error);
    header.payload_length = 0;  // No payload for errors

    osMutexAcquire(usb_flush_mutex, osWaitForever);
    tud_cdc_n_write(cdc_interface, (uint8_t*)&header, PACKET_HEADER_SIZE);
    tud_cdc_n_write_flush(cdc_interface);
    osMutexRelease(usb_flush_mutex);
}

/**
 * @brief Initialize USB OTG HS peripheral hardware (clocks, GPIO, PHY)
 * Called before tusb_init() since TinyUSB DCD doesn't configure hardware
 */
static void usb_hardware_init(void) {
    GPIO_InitTypeDef GPIO_InitStruct = {0};
    RCC_PeriphCLKInitTypeDef PeriphClkInitStruct = {0};

    // Configure USB peripheral clock to use HSI48
    PeriphClkInitStruct.PeriphClockSelection = RCC_PERIPHCLK_USB;
    PeriphClkInitStruct.UsbClockSelection = RCC_USBCLKSOURCE_HSI48;
    if (HAL_RCCEx_PeriphCLKConfig(&PeriphClkInitStruct) != HAL_OK) {
        Error_Handler();
    }

    // Enable USB voltage detector
    HAL_PWREx_EnableUSBVoltageDetector();

    // Enable GPIO clocks for USB ULPI pins
    __HAL_RCC_GPIOC_CLK_ENABLE();
    __HAL_RCC_GPIOA_CLK_ENABLE();
    __HAL_RCC_GPIOB_CLK_ENABLE();

    // Configure USB_OTG_HS ULPI pins
    // PC0 -> USB_OTG_HS_ULPI_STP
    // PC2_C -> USB_OTG_HS_ULPI_DIR
    // PC3_C -> USB_OTG_HS_ULPI_NXT
    GPIO_InitStruct.Pin = GPIO_PIN_0 | GPIO_PIN_2 | GPIO_PIN_3;
    GPIO_InitStruct.Mode = GPIO_MODE_AF_PP;
    GPIO_InitStruct.Pull = GPIO_NOPULL;
    GPIO_InitStruct.Speed = GPIO_SPEED_FREQ_VERY_HIGH;
    GPIO_InitStruct.Alternate = GPIO_AF10_OTG1_HS;
    HAL_GPIO_Init(GPIOC, &GPIO_InitStruct);

    // PA3 -> USB_OTG_HS_ULPI_D0
    // PA5 -> USB_OTG_HS_ULPI_CK
    GPIO_InitStruct.Pin = GPIO_PIN_3 | GPIO_PIN_5;
    GPIO_InitStruct.Mode = GPIO_MODE_AF_PP;
    GPIO_InitStruct.Pull = GPIO_NOPULL;
    GPIO_InitStruct.Speed = GPIO_SPEED_FREQ_VERY_HIGH;
    GPIO_InitStruct.Alternate = GPIO_AF10_OTG1_HS;
    HAL_GPIO_Init(GPIOA, &GPIO_InitStruct);

    // PB0, PB1, PB5, PB10-13 -> USB_OTG_HS_ULPI_D1-D7
    GPIO_InitStruct.Pin = GPIO_PIN_0 | GPIO_PIN_1 | GPIO_PIN_10 | GPIO_PIN_11 |
                          GPIO_PIN_12 | GPIO_PIN_13 | GPIO_PIN_5;
    GPIO_InitStruct.Mode = GPIO_MODE_AF_PP;
    GPIO_InitStruct.Pull = GPIO_NOPULL;
    GPIO_InitStruct.Speed = GPIO_SPEED_FREQ_VERY_HIGH;
    GPIO_InitStruct.Alternate = GPIO_AF10_OTG1_HS;
    HAL_GPIO_Init(GPIOB, &GPIO_InitStruct);

    // Enable USB OTG HS peripheral and ULPI clocks
    __HAL_RCC_USB_OTG_HS_CLK_ENABLE();
    __HAL_RCC_USB_OTG_HS_ULPI_CLK_ENABLE();

    // Enable USB OTG HS interrupt with priority 5 (FreeRTOS compatible)
    HAL_NVIC_SetPriority(OTG_HS_IRQn, 5, 0);
    HAL_NVIC_EnableIRQ(OTG_HS_IRQn);
}

/**
 * @brief USB Device Task - Highest Priority
 * Runs tud_task() which processes all USB events
 * CRITICAL: Must be initialized AFTER FreeRTOS starts, not before
 */
void usb_device_task(void* param) {
    (void)param;

    // Initialize USB hardware (clocks, GPIO, PHY) before TinyUSB init
    // TinyUSB DCD driver only configures USB peripheral registers, not clocks/GPIO
    usb_hardware_init();

    tusb_rhport_init_t dev_init = {.role = TUSB_ROLE_DEVICE, .speed = TUSB_SPEED_HIGH};
    tusb_init(BOARD_TUD_RHPORT, &dev_init);

    // Wait a bit for USB to stabilize
    osDelay(100);

    // RTOS forever loop
    while (1) {
        tud_task();

        // flush CDC writes
        for (uint8_t itf = 0; itf < CFG_TUD_CDC; itf++) {
            tud_cdc_n_write_flush(itf);
        }

        osDelay(1);
    }
}

/**
 * @brief USB speed test - streams test data to measure throughput
 * @param test_size_kb: Size of test data in KB
 * @param cdc_port: CDC interface to use (CDC_MAIN or CDC_LOGIC)
 * @return SNAP_OK on success, negative on error
 */
static int usb_speed_test(uint32_t test_size_kb, uint8_t cdc_port) {
    uint32_t total_bytes = test_size_kb * 1024;

    // Send response header with metadata (total bytes to be sent)
    PacketResponseHeader header = {.start_marker = PACKET_START_MARKER_RESPONSE,
                                   .status = PACKET_STATUS_OK,
                                   .payload_length = sizeof(total_bytes)};

    tud_cdc_n_write(cdc_port, (uint8_t*)&header, PACKET_HEADER_SIZE);
    tud_cdc_n_write(cdc_port, (uint8_t*)&total_bytes, sizeof(total_bytes));
    tud_cdc_n_write_flush(cdc_port);

    // Pre-fill sample_buffer with test pattern (incrementing 0x00-0xFF)
    // This avoids recreating the pattern on every iteration
    const uint32_t PATTERN_SIZE = 4096;  // Use 4KB pattern (reuse existing buffer)
    for (uint32_t i = 0; i < PATTERN_SIZE && i < SAMPLE_BUF_SIZE; i++) {
        sample_buffer[i] = (uint8_t)(i & 0xFF);
    }

    // Stream test data - tight loop with NO osDelay()
    uint32_t bytes_sent = 0;
    while (bytes_sent < total_bytes) {
        uint32_t bytes_remaining = total_bytes - bytes_sent;

        // Try to write as much as TinyUSB will accept
        // Use pattern buffer, wrapping if needed
        uint32_t bytes_to_send =
            (bytes_remaining < PATTERN_SIZE) ? bytes_remaining : PATTERN_SIZE;

        uint32_t written = tud_cdc_n_write(cdc_port, sample_buffer, bytes_to_send);
        bytes_sent += written;

        // Process USB events - NO delay!
        tud_task();
    }

    tud_cdc_n_write_flush(cdc_port);

    // Wait for transmission complete - tight loop, NO osDelay()
    const uint32_t MIN_AVAILABLE = 64;
    while (tud_cdc_n_write_available(cdc_port) < MIN_AVAILABLE) {
        tud_task();
    }

    return SNAP_OK;
}

void chunk_stream_task(void* param) {
    (void)param;

    while (1) {
        // Sleep until work arrives
        osSemaphoreAcquire(chunkStartSemaphore, osWaitForever);

        chunk_cancel_requested = 0;
        osMutexAcquire(chunkRequestMutex, osWaitForever);
        chunk_task_running = 1;
        osMutexRelease(chunkRequestMutex);

        while (1) {
            if (chunk_cancel_requested) {
                // Drain request queue
                osMutexAcquire(chunkRequestMutex, osWaitForever);
                num_chunks_requested = 0;
                osMutexRelease(chunkRequestMutex);

                chunk_cancel_requested = 0;
                break;
            }

            uint32_t chunks_to_send = 0;

            // Safely pull counter under mutex
            osMutexAcquire(chunkRequestMutex, osWaitForever);
            chunks_to_send = num_chunks_requested;
            num_chunks_requested = 0;
            osMutexRelease(chunkRequestMutex);

            if (chunks_to_send == 0) {
                break;
            }

            // Blocking stream execution
            command_get_chunk(chunks_to_send, chunk_cdc_port, chunk_command,
                              &chunk_cancel_requested);
        }

        osMutexAcquire(chunkRequestMutex, osWaitForever);
        chunk_task_running = 0;
        osMutexRelease(chunkRequestMutex);
    }
}

void tud_cdc_rx_cb(uint8_t itf) { osSemaphoreRelease(processCommandSemaphore); }
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
int main(void) {
    /* MPU Configuration--------------------------------------------------------*/
    MPU_Config();

    /* MCU Configuration--------------------------------------------------------*/

    /* Reset of all peripherals, Initializes the Flash interface and the Systick. */
    HAL_Init();

    /* Configure the system clock */
    SystemClock_Config();

    /* Initialize all configured peripherals */
    MX_GPIO_Init();
    MX_DMA_Init();
    MX_USART1_UART_Init();
    MX_I2C1_Init();
    MX_SPI1_Init();
    MX_USB_OTG_HS_PCD_Init();
    /* USER CODE BEGIN 2 */
    // CRITICAL: Do NOT call tud_init() here!
    // USB initialization MUST happen inside usb_device_task AFTER FreeRTOS starts
    // Calling it here will cause race conditions with USB interrupts and FreeRTOS
    /* USER CODE END 2 */

    /* Init scheduler */
    osKernelInitialize();

    /* USER CODE BEGIN RTOS_MUTEX */
    // Create mutexes for resource protection
    usb_flush_mutex = osMutexNew(NULL);
    i2cMutexHandle = osMutexNew(&mutex_attributes);
    spiSemaphoreHandle = osSemaphoreNew(1, 1, NULL);

    if (i2cMutexHandle == NULL || spiSemaphoreHandle == NULL) {
        Error_Handler();  // Mutex creation failed
    }
    processCommandSemaphore = osSemaphoreNew(1, 0, NULL);

    chunkStartSemaphore = osSemaphoreNew(1, 0, NULL);
    chunkRequestMutex = osMutexNew(NULL);
    /* USER CODE END RTOS_MUTEX */

    /* USER CODE BEGIN RTOS_SEMAPHORES */
    /* add semaphores, ... */
    /* USER CODE END RTOS_SEMAPHORES */

    /* USER CODE BEGIN RTOS_TIMERS */
    /* start timers, add new ones, ... */
    /* USER CODE END RTOS_TIMERS */

    /* USER CODE BEGIN RTOS_QUEUES */
    /* add queues, ... */
    /* USER CODE END RTOS_QUEUES */

    /* Create the thread(s) */
    /* creation of defaultTask */
    defaultTaskHandle = osThreadNew(StartDefaultTask, NULL, &defaultTask_attributes);

    /* USER CODE BEGIN RTOS_THREADS */
    // Create FreeRTOS tasks in priority order
    // CRITICAL: USB task MUST be created so USB init happens after scheduler starts
    usbTaskHandle = osThreadNew(usb_device_task, NULL, &usb_task_attributes);
    if (usbTaskHandle == NULL) {
        Error_Handler();  // USB task creation failed
    }

    commandTaskHandle = osThreadNew(command_handler_task, NULL, &command_task_attributes);
    if (commandTaskHandle == NULL) {
        Error_Handler();  // Command task creation failed
    }

    chunkTaskHandle = osThreadNew(chunk_stream_task, NULL, &chunk_task_attr);

    if (chunkStartSemaphore == NULL || chunkRequestMutex == NULL ||
        chunkTaskHandle == NULL) {
        Error_Handler();  // Command task creation failed
    }

    // Initialize Logic Analyzer Streaming
    la_stream_init();
    /* USER CODE END RTOS_THREADS */

    /* USER CODE BEGIN RTOS_EVENTS */
    /* add events, ... */
    /* USER CODE END RTOS_EVENTS */

    /* Initialize leds */
    BSP_LED_Init(LED_GREEN);
    BSP_LED_Init(LED_YELLOW);
    BSP_LED_Init(LED_RED);

    /* Initialize USER push-button, will be used to trigger an interrupt each time it's
     * pressed.*/
    BSP_PB_Init(BUTTON_USER, BUTTON_MODE_EXTI);

    /* Initialize COM1 port (115200, 8 bits (7-bit data + 1 stop bit), no parity */
    bsp_com_init.BaudRate = 115200;
    bsp_com_init.WordLength = COM_WORDLENGTH_8B;
    bsp_com_init.StopBits = COM_STOPBITS_1;
    bsp_com_init.Parity = COM_PARITY_NONE;
    bsp_com_init.HwFlowCtl = COM_HWCONTROL_NONE;
    if (BSP_COM_Init(COM1, &bsp_com_init) != BSP_ERROR_NONE) {
        Error_Handler();
    }

    /* Start scheduler */
    osKernelStart();

    /* We should never get here as control is now taken by the scheduler */

    /* Infinite loop */
    /* USER CODE BEGIN WHILE */
    // Code never reaches here after osKernelStart()
    // All functionality is now in FreeRTOS tasks
    while (1) {
        /* USER CODE END WHILE */

        /* USER CODE BEGIN 3 */
    }
    /* USER CODE END 3 */
}

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
/* USER CODE BEGIN Header_StartDefaultTask */
/**
 * @brief  Function implementing the defaultTask thread.
 * @param  argument: Not used
 * @retval None
 */
/* USER CODE END Header_StartDefaultTask */
void StartDefaultTask(void* argument) {
    /* USER CODE BEGIN 5 */
    /* Infinite loop */
    osDelay(500);
    for (;;) {
        osDelay(1000);
    }
    /* USER CODE END 5 */
}

/* MPU Configuration */

void MPU_Config(void) {
    MPU_Region_InitTypeDef MPU_InitStruct = {0};

    /* Disables the MPU */
    HAL_MPU_Disable();

    /** Initializes and configures the Region and the memory to be protected
     */
    MPU_InitStruct.Enable = MPU_REGION_ENABLE;
    MPU_InitStruct.Number = MPU_REGION_NUMBER0;
    MPU_InitStruct.BaseAddress = 0x0;
    MPU_InitStruct.Size = MPU_REGION_SIZE_4GB;
    MPU_InitStruct.SubRegionDisable = 0x87;
    MPU_InitStruct.TypeExtField = MPU_TEX_LEVEL0;
    MPU_InitStruct.AccessPermission = MPU_REGION_NO_ACCESS;
    MPU_InitStruct.DisableExec = MPU_INSTRUCTION_ACCESS_DISABLE;
    MPU_InitStruct.IsShareable = MPU_ACCESS_SHAREABLE;
    MPU_InitStruct.IsCacheable = MPU_ACCESS_NOT_CACHEABLE;
    MPU_InitStruct.IsBufferable = MPU_ACCESS_NOT_BUFFERABLE;

    HAL_MPU_ConfigRegion(&MPU_InitStruct);
    /* Enables the MPU */
    HAL_MPU_Enable(MPU_PRIVILEGED_DEFAULT);
}

/**
 * @brief  Period elapsed callback in non blocking mode
 * @note   This function is called  when TIM6 interrupt took place, inside
 * HAL_TIM_IRQHandler(). It makes a direct call to HAL_IncTick() to increment
 * a global variable "uwTick" used as application time base.
 * @param  htim : TIM handle
 * @retval None
 */
void HAL_TIM_PeriodElapsedCallback(TIM_HandleTypeDef* htim) {
    if (htim->Instance == TIM6) {
        HAL_IncTick();
    }
}

/**
 * @brief  This function is executed in case of error occurrence.
 * @retval None
 */
void Error_Handler(void) {
    /* USER CODE BEGIN Error_Handler_Debug */
    /* User can add his own implementation to report the HAL error return state */
    __disable_irq();
    while (1) {
    }
    /* USER CODE END Error_Handler_Debug */
}
#ifdef USE_FULL_ASSERT
/**
 * @brief  Reports the name of the source file and the source line number
 *         where the assert_param error has occurred.
 * @param  file: pointer to the source file name
 * @param  line: assert_param error line source number
 * @retval None
 */
void assert_failed(uint8_t* file, uint32_t line) {
    /* USER CODE BEGIN 6 */
    /* User can add his own implementation to report the file name and line number,
       ex: printf("Wrong parameters value: file %s on line %d\r\n", file, line) */
    /* USER CODE END 6 */
}
#endif /* USE_FULL_ASSERT */

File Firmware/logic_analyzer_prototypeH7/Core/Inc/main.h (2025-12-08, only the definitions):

#define B1_Pin GPIO_PIN_13
#define B1_GPIO_Port GPIOC
#define D0_Pin GPIO_PIN_0
#define D0_GPIO_Port GPIOF
#define D1_Pin GPIO_PIN_1
#define D1_GPIO_Port GPIOF
#define D2_Pin GPIO_PIN_2
#define D2_GPIO_Port GPIOF
#define D3_Pin GPIO_PIN_3
#define D3_GPIO_Port GPIOF
#define D4_Pin GPIO_PIN_4
#define D4_GPIO_Port GPIOF
#define D5_Pin GPIO_PIN_5
#define D5_GPIO_Port GPIOF
#define D6_Pin GPIO_PIN_6
#define D6_GPIO_Port GPIOF
#define D7_Pin GPIO_PIN_7
#define D7_GPIO_Port GPIOF
#define D8_Pin GPIO_PIN_8
#define D8_GPIO_Port GPIOF
#define D9_Pin GPIO_PIN_9
#define D9_GPIO_Port GPIOF
#define LED_GREEN_Pin GPIO_PIN_0
#define LED_GREEN_GPIO_Port GPIOB
#define LED_RED_Pin GPIO_PIN_14
#define LED_RED_GPIO_Port GPIOB
#define STLK_VCP_RX_Pin GPIO_PIN_8
#define STLK_VCP_RX_GPIO_Port GPIOD
#define STLK_VCP_TX_Pin GPIO_PIN_9
#define STLK_VCP_TX_GPIO_Port GPIOD
#define SPI_CS_Pin GPIO_PIN_14
#define SPI_CS_GPIO_Port GPIOD
#define SWDIO_Pin GPIO_PIN_13
#define SWDIO_GPIO_Port GPIOA
#define SWCLK_Pin GPIO_PIN_14
#define SWCLK_GPIO_Port GPIOA
#define LED_YELLOW_Pin GPIO_PIN_1
#define LED_YELLOW_GPIO_Port GPIOE

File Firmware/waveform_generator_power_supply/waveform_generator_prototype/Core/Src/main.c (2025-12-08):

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
/* Includes ------------------------------------------------------------------*/
#include "main.h"
#include "cmsis_os.h"

/* USER CODE BEGIN Includes */
#include <stdio.h>
#include "waveform_generator_ll.h"
#include "power_supply_ll.h"
#include "snap_module.h"
/* USER CODE END Includes */

/* USER CODE BEGIN PTD */
extern void CommandProcessingTask(void *argument);
/* USER CODE END PTD */

DAC_HandleTypeDef hdac1;
DMA_HandleTypeDef hdma_dac1_ch1;

I2C_HandleTypeDef hi2c1;
I2C_HandleTypeDef hi2c2;

UART_HandleTypeDef hlpuart1;

TIM_HandleTypeDef htim2;
TIM_HandleTypeDef htim3;

/* Definitions for defaultTask */
osThreadId_t defaultTaskHandle;
const osThreadAttr_t defaultTask_attributes = {
  .name = "defaultTask",
  .priority = (osPriority_t) osPriorityNormal,
  .stack_size = 128 * 4
};
/* USER CODE BEGIN PV */
osThreadId_t commandProcessingTaskHandle;
const osThreadAttr_t commandProcessingTask_attributes = {
		.name = "commandProcessing",
		.stack_size = 128 * 4 * 4,
		.priority = (osPriority_t) osPriorityRealtime
};


osThreadId_t psuHealthTaskHandle;
const osThreadAttr_t psuHealthTask_attributes = {
		.name = "psuHealth",
		.stack_size = 128 * 4 * 4,
		.priority = (osPriority_t) osPriorityNormal
};

PSUObject psu;
AP33772S_t ap;

/* USER CODE END PV */

void SystemClock_Config(void);
static void MX_GPIO_Init(void);
static void MX_DMA_Init(void);
static void MX_TIM2_Init(void);
static void MX_DAC1_Init(void);
static void MX_I2C1_Init(void);
static void MX_TIM3_Init(void);
static void MX_LPUART1_UART_Init(void);
static void MX_I2C2_Init(void);
void StartDefaultTask(void *argument);

/* USER CODE BEGIN PFP */
extern void i2c_fsm_watchdog_callback();
/* USER CODE END PFP */

/* USER CODE BEGIN 0 */
void processCommand(CommandMessage *cmd, CommandResponse *resp) {

	if(cmd->code == COMMAND_SET_WAVEFORM){
		commandSetWaveform(cmd,resp);


	}else if(cmd->code >= COMMAND_PD_ALIVE && cmd->code <= COMMAND_PD_REQUEST_OUTPUT){
		parsePDCommand(&psu, cmd, resp);
	}
	else{
		// INVALID COMMAND

	    // Set response code to SUCCESS
	    resp->code = RESPONSE_INVALID;

	    // Set data length to 0
	    resp->data_len = 0;
	}
}
/* USER CODE END 0 */

/**
  * @brief  The application entry point.
  * @retval int
  */
int main(void)
{

  /* MCU Configuration--------------------------------------------------------*/

  /* Reset of all peripherals, Initializes the Flash interface and the Systick. */
  HAL_Init();

  /* Configure the system clock */
  SystemClock_Config();

  /* Initialize all configured peripherals */
  MX_GPIO_Init();
  MX_DMA_Init();
  MX_TIM2_Init();
  MX_DAC1_Init();
  MX_I2C1_Init();
  MX_TIM3_Init();
  MX_LPUART1_UART_Init();
  MX_I2C2_Init();
  /* USER CODE BEGIN 2 */

  //Command processing i2c init
  HAL_I2C_EnableListen_IT(&hi2c1);

  initPSUObject(&psu, &ap, &hi2c2);

  /* USER CODE END 2 */

  /* Init scheduler */
  osKernelInitialize();

  /* USER CODE BEGIN RTOS_MUTEX */
  /* add mutexes, ... */
  /* USER CODE END RTOS_MUTEX */

  /* USER CODE BEGIN RTOS_SEMAPHORES */
  /* add semaphores, ... */
  /* USER CODE END RTOS_SEMAPHORES */

  /* USER CODE BEGIN RTOS_TIMERS */
  /* start timers, add new ones, ... */
  /* USER CODE END RTOS_TIMERS */

  /* USER CODE BEGIN RTOS_QUEUES */
  /* add queues, ... */
  /* USER CODE END RTOS_QUEUES */

  /* Create the thread(s) */
  /* creation of defaultTask */
  defaultTaskHandle = osThreadNew(StartDefaultTask, NULL, &defaultTask_attributes);

  /* USER CODE BEGIN RTOS_THREADS */
  /* add threads, ... */
  commandProcessingTaskHandle = osThreadNew(CommandProcessingTask, NULL, &commandProcessingTask_attributes);

  // AP33772S Recovery Task
  psuHealthTaskHandle = osThreadNew(PDHealthTask, &psu, &psuHealthTask_attributes);


  /* USER CODE END RTOS_THREADS */

  /* USER CODE BEGIN RTOS_EVENTS */
  /* add events, ... */
  /* USER CODE END RTOS_EVENTS */

  /* Start scheduler */
  osKernelStart();

  /* We should never get here as control is now taken by the scheduler */

  /* Infinite loop */
  /* USER CODE BEGIN WHILE */
  while (1)
  {
    /* USER CODE END WHILE */

    /* USER CODE BEGIN 3 */
  }
  /* USER CODE END 3 */
}

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
/* USER CODE BEGIN 4 */
#ifdef __GNUC__
#define PUTCHAR_PROTOTYPE int __io_putchar(int ch)
#else
  #define PUTCHAR_PROTOTYPE int fputc(int ch, FILE *f)
#endif /* __GNUC__ */
PUTCHAR_PROTOTYPE
{
  HAL_UART_Transmit(&hlpuart1, (uint8_t *)&ch, 1, 0xFFFF);
  return ch;
}
/* USER CODE END 4 */

/* USER CODE BEGIN Header_StartDefaultTask */
/**
  * @brief  Function implementing the defaultTask thread.
  * @param  argument: Not used
  * @retval None
  */
/* USER CODE END Header_StartDefaultTask */
void StartDefaultTask(void *argument)
{
  /* USER CODE BEGIN 5 */
  /* Infinite loop */
  for(;;)
  {
    osDelay(1);
  }
  /* USER CODE END 5 */
}

/**
  * @brief  Period elapsed callback in non blocking mode
  * @note   This function is called  when TIM7 interrupt took place, inside
  * HAL_TIM_IRQHandler(). It makes a direct call to HAL_IncTick() to increment
  * a global variable "uwTick" used as application time base.
  * @param  htim : TIM handle
  * @retval None
  */
void HAL_TIM_PeriodElapsedCallback(TIM_HandleTypeDef *htim)
{
  /* USER CODE BEGIN Callback 0 */
  if (htim->Instance == TIM3)
  {
  	i2c_fsm_watchdog_callback();
  }
  /* USER CODE END Callback 0 */
  if (htim->Instance == TIM7)
  {
    HAL_IncTick();
  }
}

/**
  * @brief  This function is executed in case of error occurrence.
  * @retval None
  */
void Error_Handler(void)
{
  /* USER CODE BEGIN Error_Handler_Debug */
  /* User can add his own implementation to report the HAL error return state */
  __disable_irq();
  while (1)
  {
  }
  /* USER CODE END Error_Handler_Debug */
}
#ifdef USE_FULL_ASSERT
/**
  * @brief  Reports the name of the source file and the source line number
  *         where the assert_param error has occurred.
  * @param  file: pointer to the source file name
  * @param  line: assert_param error line source number
  * @retval None
  */
void assert_failed(uint8_t *file, uint32_t line)
{
  /* USER CODE BEGIN 6 */
  /* User can add his own implementation to report the file name and line number,
     ex: printf("Wrong parameters value: file %s on line %d\r\n", file, line) */
  /* USER CODE END 6 */
}
#endif /* USE_FULL_ASSERT */

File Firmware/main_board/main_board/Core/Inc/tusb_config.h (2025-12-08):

/*
 * The MIT License (MIT)
 *
 * Copyright (c) 2019 Ha Thach (tinyusb.org)
 *
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
 */

#ifndef _TUSB_CONFIG_H_
#define _TUSB_CONFIG_H_

#ifdef __cplusplus
extern "C" {
#endif

//--------------------------------------------------------------------+
// Board Specific Configuration
//--------------------------------------------------------------------+

// RHPort number used for device can be defined by board.mk, default to port 0
#ifndef BOARD_TUD_RHPORT
#define BOARD_TUD_RHPORT 1
#endif

// RHPort max operational speed can defined by board.mk
#ifndef BOARD_TUD_MAX_SPEED
#define BOARD_TUD_MAX_SPEED OPT_MODE_HIGH_SPEED  // OPT_MODE_HIGH_SPEED for high speed
#endif
#define CFG_TUSB_RHPORT1_MODE (OPT_MODE_DEVICE | OPT_MODE_HIGH_SPEED)

//--------------------------------------------------------------------
// COMMON CONFIGURATION
//--------------------------------------------------------------------

// defined by board.mk
#define CFG_TUSB_MCU OPT_MCU_STM32H7
#ifndef CFG_TUSB_MCU
#error CFG_TUSB_MCU must be defined
#endif

#ifndef CFG_TUSB_OS
#define CFG_TUSB_OS OPT_OS_FREERTOS
#endif

#ifndef CFG_TUSB_DEBUG
#define CFG_TUSB_DEBUG 0
#endif

// Enable Device stack
#define CFG_TUD_ENABLED 1

// Default is max speed that hardware controller could support with on-chip PHY
#define CFG_TUD_MAX_SPEED BOARD_TUD_MAX_SPEED

/* USB DMA on some MCUs can only access a specific SRAM region with restriction on
 * alignment. Tinyusb use follows macros to declare transferring memory so that they can
 * be put into those specific section. e.g
 * - CFG_TUSB_MEM SECTION : __attribute__ (( section(".usb_ram") ))
 * - CFG_TUSB_MEM_ALIGN   : __attribute__ ((aligned(4)))
 */
#ifndef CFG_TUSB_MEM_SECTION
#define CFG_TUSB_MEM_SECTION
#endif

#ifndef CFG_TUSB_MEM_ALIGN
#define CFG_TUSB_MEM_ALIGN __attribute__((aligned(4)))
#endif

//--------------------------------------------------------------------
// DEVICE CONFIGURATION
//--------------------------------------------------------------------

#ifndef CFG_TUD_ENDPOINT0_SIZE
#define CFG_TUD_ENDPOINT0_SIZE 64
#endif

//------------- CLASS -------------//
#define CFG_TUD_CDC 2
#define CFG_TUD_MSC 0
#define CFG_TUD_HID 0
#define CFG_TUD_MIDI 0
#define CFG_TUD_VENDOR 0

// CDC FIFO size of TX and RX
#define CFG_TUD_CDC_RX_BUFSIZE (TUD_OPT_HIGH_SPEED ? 1024 : 512)
#define CFG_TUD_CDC_TX_BUFSIZE (TUD_OPT_HIGH_SPEED ? 1024 : 512)

// CDC Endpoint transfer buffer size, more is faster
#define CFG_TUD_CDC_EP_BUFSIZE (TUD_OPT_HIGH_SPEED ? 512 : 64)

#ifdef __cplusplus
}
#endif

#endif /* _TUSB_CONFIG_H_ */

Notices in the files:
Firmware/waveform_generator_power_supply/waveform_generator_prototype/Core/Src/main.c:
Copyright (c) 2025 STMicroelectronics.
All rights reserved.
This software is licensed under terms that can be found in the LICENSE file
